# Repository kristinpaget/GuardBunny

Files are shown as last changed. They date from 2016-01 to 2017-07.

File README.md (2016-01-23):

# GuardBunny
## An active RFID shield

**tl;dr: Send the contents of the "Manufacturing" folder to any PCBA shop and they should be able to make you a batch of GuardBunnies.**

In this repository:

- Eagle Files:

Schematic, PCB layout, and library for the counter chip.  Built with Eagle for Mac 7.5.0.

- Logo

GuardBunny logo design

- Manufacturing

Gerber files (including Excellon drill data), Bill of Materials, component placement co-ordinates.

- Presentation

The slides.  Link to follow to video of the talk.

- schematic.png

Exactly what it says on the tin :D

If you would be interested in joining a group order for GuardBunnies, send me an email at iwantabunny@tombom.co.uk and tell me how many you'd like - bear in mind they'll be $15-20 each unless we can get some quantity going.

Released under Creative Commons license Attribution-ShareAlike 4.0 International (CC BY-SA 4.0) - http://creativecommons.org/licenses/by-sa/4.0/

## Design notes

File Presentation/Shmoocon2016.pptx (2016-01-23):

## Be Free, Little Guardbunny!

Presented at Shmoocon 2016

- Kristin Paget
- Director of Security Data Cloud

- kristin@tombom.co.uk
- kpaget@salesforce.com
- @kristinpaget

## Much love and many thanks

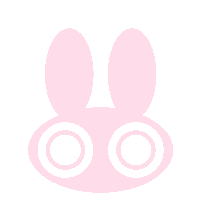
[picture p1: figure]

- JP Martin
- Henry and the Recursion crew
- Salesforce
- All the engineers that I've talked at about this :)
- My wife and her m4d 5MD 5k1llz <3

## Theory

## What is GuardBunny?

- An active RFID shield.
  - Conventional shields attempt to block the signal
    - Stronger signals saturate and eventually penetrate
  - GuardBunny absorbs the signal and uses it
    - Stronger signals? No problem!
- It's a lot like an RFID tag
  - In a lot of ways it is an RFID tag
  - In other ways...not so much :)
- NB: “RFID” = “Contactless” = “NFC” = “WTFEver”.
  - As long as it's at 13.56MHz

## GuardBunny vs RFID

Source: placeholder

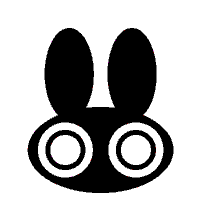
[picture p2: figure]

| | MIFARE Classic | iClass
Passively powered, active device | ✔ | ✔ | ✔
Communicates via load modulation | ✔ | ✔ | ✔
Memory | 4 bits | Up to 4K | Up to 4K
Non-volatile storage | ✘ | ✔ | ✔
Has CPU | ✘ | ✔ | ✔

## Flow of Operation

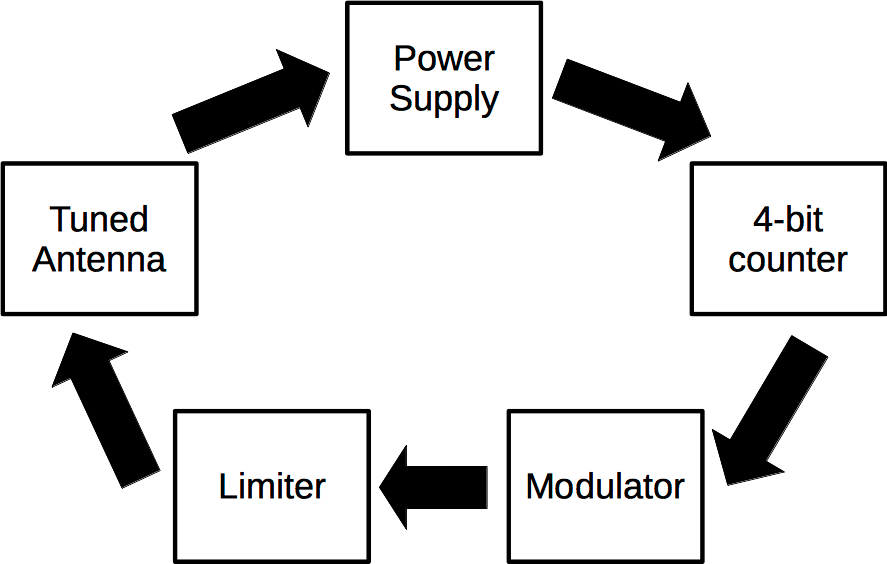
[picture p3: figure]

## Why a 4-bit counter?

- ISO 14443 specifies an ~847KHz subcarrier
  - A.K.A. fc/16 = carrier frequency / 16
  - 1 bit duration = 8 periods of the subcarrier
- In these systems fc/16 is critical
- 4 bit counter = 16 possible states
- 16 states into a modulator gives you fc/16
- GuardBunny speaks ISO14443! :)

## So what’s with the fc/16?

- The tag communicates via fc/16
- GuardBunny outputs fc/16
- GuardBunny doesn't have to be loudest
  - If it can flip a single bit, it wins
  - If it can de-sync the reader's timing, it wins
  - If it can confuse the reader at all, it wins
- Loud enough to be heard is good enough.

## Electrical

## Schematic

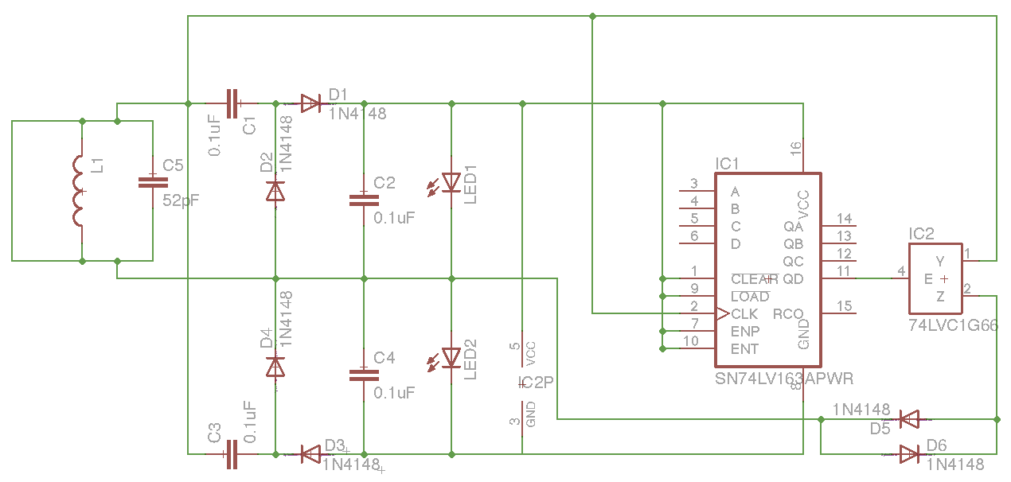
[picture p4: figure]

## Stage 1: Antenna

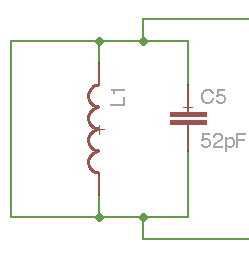
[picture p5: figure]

- Nothing too special
- Shorted for the PCB layout
  - Electrically, it kinda is
- Tuning is tricksy.
  - But critical!
  - Use another PCB to tune.

## Stage 2: Power Supply

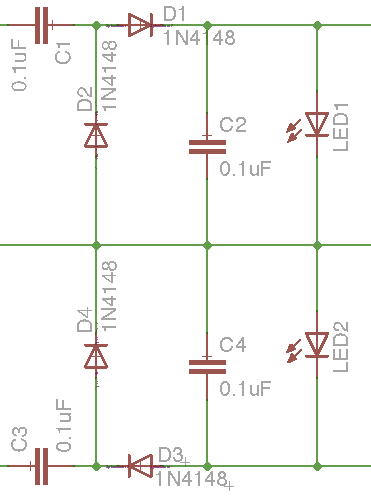
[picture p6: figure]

- Two halves of a full-wave rectifier
  - The middle line is “ground”
- C1 & C3 decouple the supply
- D2&4 compensate for D1&3
  - While doubling voltage
  - 2 phases doubles voltage again
- C2 & C4 are tanks
- LED1 & 2 act as voltage limiters
- Very low drop-out

## Stage 3: 4-bit counter

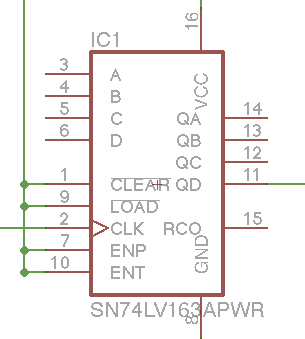
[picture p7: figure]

- 74LV163, but any binary counter is fine
- Key specification rating: Turn-on voltage
  - (74LV is 2V)
- Check datasheets for weird pins
- Make sure it'll take a 13.56MHz clock...

## Stage 4: Modulator

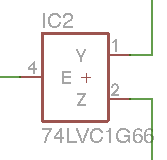
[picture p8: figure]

- “Analog switch”
- Switching speed and voltage rating are crucial
- When E is high, short Y and Z together.
- Y and Z go to coil, E now load-modulates

## Stage 5: Limiter

- The counter gets its clock from the coil
- If the coil is shorted there is no clock!
- Solution: don't short the coil completely.
- D5 & D6 guarantee at least 0.7V on the coil

## Schematic Redux

## Demo

## Improvements

## That’s v1. What would v2 look like?

- Antenna geometry matching
  - PSU trickery
- Counter chip input impedance
  - Constant-current regulators to the rescue!
- Modulator logic
  - Different approaches
- Power supply
  - Switchmode for lower dropout?
- Additional alerts

## Capturing the Flux

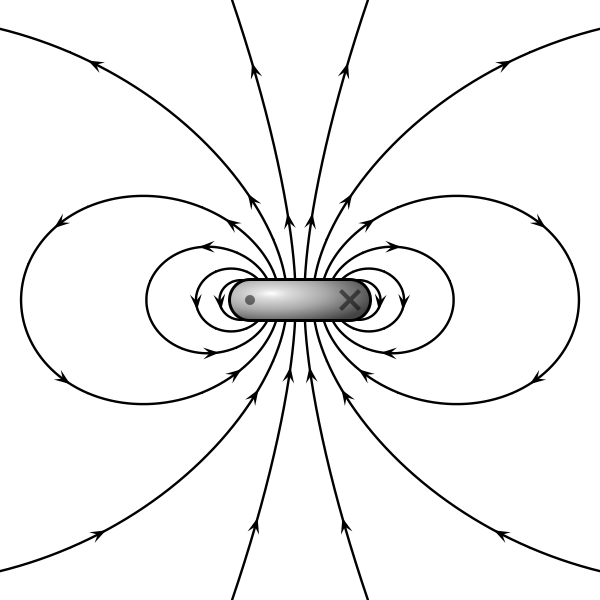
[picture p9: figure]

- Magnetic field lines flow through the coil
- If coils don't match, not all flux is matched
- If flux is mismatched, power is mismatched
- Power the tag but not GuardBunny :(

## Solution: Antenna arrays

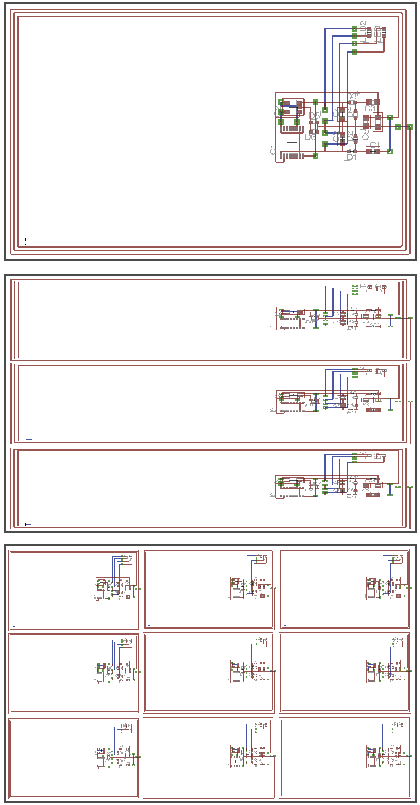
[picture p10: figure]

- Use lots of antennas!
- Crude: Multiple GuardBunny circuits per instance
- Better: give each antenna a PSU, combine in series
- Ultimate: Manipulate phase and combine at the antenna.
- Once powered, modulate all the antennas as one

## Counter input

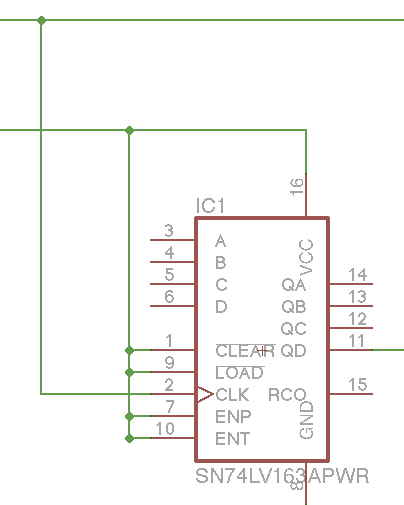
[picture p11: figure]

- Counter chip gets its clock directly from the coil
- Not a problem unless power is high
  - The LEDs ultimately limit coil voltage
- Protection diodes shunt away the excess
  - Killing our modulation depth in the process
- Loss of good power for no signal benefit

## Solution: Impedance trickery

- We want low impedance at low voltage
- We want the chip to turn on quickly
- We want high impedance at high voltage
- We don't want excess voltage reaching the chip
- We also don't want power from the coil to be shunted
- Simple PSU approaches don’t work!

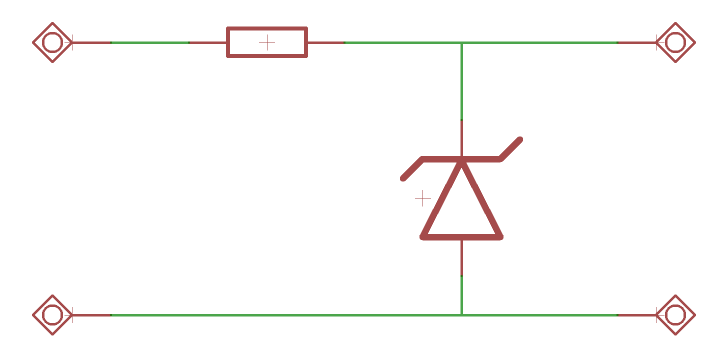
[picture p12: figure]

## Constant current regulator

- Converts constant V to constant I
- Set I very low (input impedance is known)
- Use something better than a 7805
  - Some kind of LDO regulator, probably
- Output voltage is odd
  - Efficiency vs logic thresholds

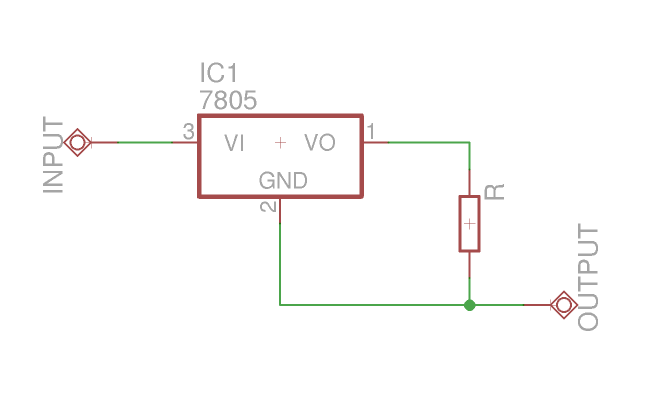
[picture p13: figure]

## Modulator logic

- The current logic:
  - If PSU is overcharged, discharge through LEDs
  - If the modulator is on, short-circuit the coil (+/- lim)
- At high energy, too much power goes to LEDs
- An alternate approach:
  - Allow PSU to charge endlessly
  - Modulator dumps power from PSU into LEDs
  - PSU recharge current back-propagates to coil
  - Phase shifts might cause problems (or fun!)

## Power supply

- The present combination works well
  - No uncompensated voltage drops, high efficiency, 4x multiplier
- Could avoid dumping power to LEDs
  - Same constant current trickery as for counter
- Could go for a higher multiplier
  - Tradeoff: more caps and diodes. Not too bad. Useful?
- Switchmode might help low-end performance
  - Very tricksy to design
- Still might get killed by lack of power

## Alerting options

- Extend the counter - bit 10 is audio
  - Several good tones at Q10-14, choose or combine
    - (Q16 && Q10) || (!Q16 && Q11) == 2-tone siren!
  - Drive a piezo with them!
- Should be enough power to drive a BLE chip
  - Increase PSU caps to stay alive longer if needed
- Lots of UI possibilities in a card form factor
  - Screen showing event count?
  - Button to disable device?

## Failure Modes

- Antennas don't match
  - Can't ever be perfect. Does “good enough” exist?
- Way, WAY too much power
  - LEDs will likely die first, releasing PSU voltage
  - Chips die pretty soon after == no more fc/16
  - Finally, PSU caps are rated at 25V (magic smoke?)
  - Use a high-voltage zener to protect against this
    - Dies eventually – but so will the tag.
- DSP to separate GB modulation from tag
- Static electricity (the counter chip is sensitive)

## Build

## Build a Batch of Bunnies

- It's designed to fit into a clamshell case
  - Counter IC is TSSOP – 1.2mm thick
  - Flex PCBs will fit, FR4 probably not
- Production costs (approx):
  - $100 / board in qty 10 (not including assembly)
  - $10 / board in qty 1,000 (including assembly)
  - $5 / board in qty 10,000 (including assembly)
- None of the parts are particularly tricksy
  - 0603 caps, SOD523 diodes, SOT23-5 modulator

## Component Selection

- Tuning caps are sensitive! Use 1%, C0G, 100V
- PSU caps not so sensitive. 10V+, 0.1uF+
- Diodes: Fast recovery is key, ideally a few ns
  - 1N4148 works fine at 4ns, but could be improved
  - Make sure your limiter diode Vf will allow clock to tick!
- Counter: Low-voltage turnon is crucial. TSSOP.
  - Any old 4-bit binary counter will work though!
- Modulator: Check voltage / current ratings.

## Component selection: LEDs

- Start by checking voltage ratings on chips
- Each LED shunts half the supply voltage
  - This sets the maximum forward voltage allowed
- Tradeoff: forward voltage
  - Higher Vf means GuardBunny is more effective
  - Lower Vf means that the LEDs turn on sooner
- Tradeoff: forward current
  - Higher If means brighter lights
  - Lower If means more effective but vulnerable to high power

## Conclusions

- It's a v1, proof-of-concept device.
- It works, but has (fixable) weaknesses
- My opinion:
  - Not yet worthy of selling as a product
  - Definitely worthy of talking about :)
- Lots of work to do – help appreciated!

## Questions?

Schematic, layout, BOM, gerbers, logos etc:
https://github.com/kristinpaget/GuardBunny

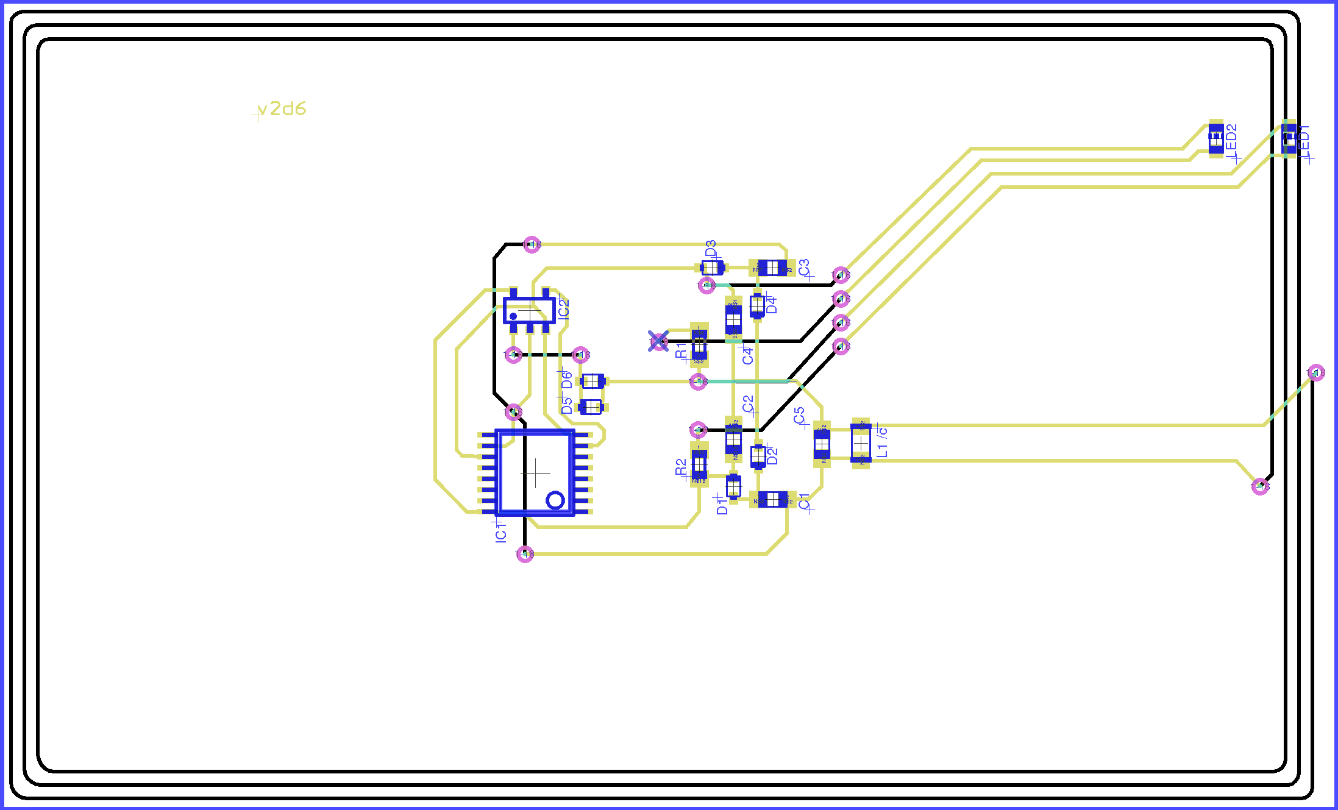
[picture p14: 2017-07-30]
DC25/GB_v2d6_layout_big.png

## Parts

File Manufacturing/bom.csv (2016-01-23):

Description | Qty | Ref des | MFG P/N | MFG | Mouser P/N
MLCC 0.1uF 25V 0603 | 4 | C1, C2, C3, C4 | VJ0603V104ZXXCW1BC | Vishay | 77-VJ0603V104ZXXCBC
MLCC 200pF 100V C0G 0603 | 1 | C5 | GRM1885C2A201JA01D | Murata | 81-GRM1885C2A201JA1D
Diode 1N4148X | 6 | D1, D2, D3, D4, D5, D6 | 1N4148X-TP | MCC | 833-1N4148X-TP
74LV163 4-bit counter | 1 | IC1 | SN74LV163APWR | TI | 595-SN74LV163APWR
74LVC1G66 analog switch | 1 | IC2 | SN74LVC1G66DBVR | TI | 595-SN74LVC1G66DBVR
DNP | 1 | L1 | DNP | DNP | DNP
RED LED | 2 | LED1, LED2 | LS Q976-NR-1 | OSRAM | 720-LSQ976-NR-1

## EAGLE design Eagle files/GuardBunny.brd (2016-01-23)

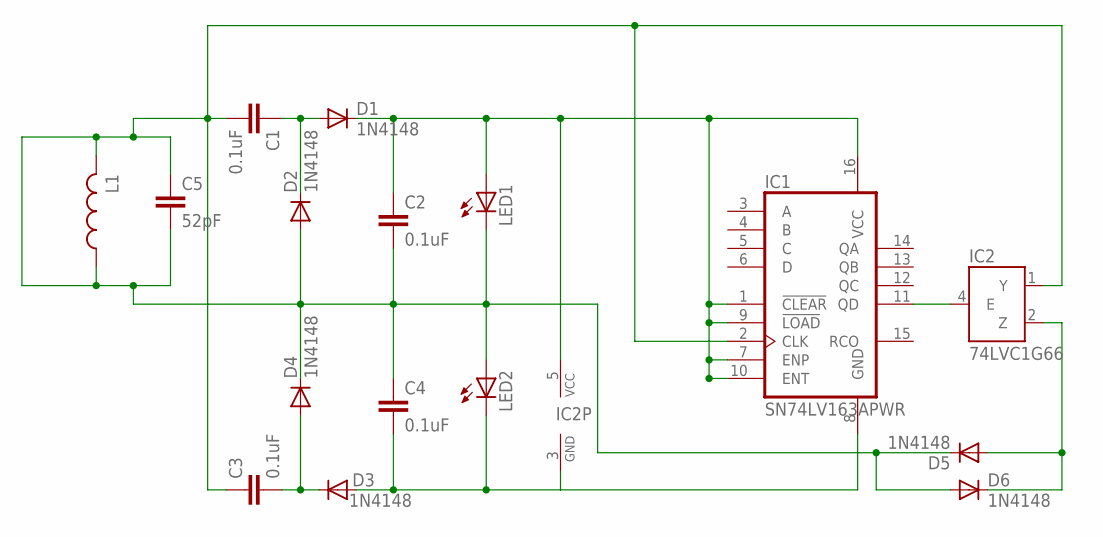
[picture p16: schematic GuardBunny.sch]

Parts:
C1, C2, C3, C4: 0.1uF; C0603
C5: 52pF; C0603
D1, D2, D3, D4, D5, D6: 1N4148; SOD523
IC1: SN74LV163APWR; TSSOP16
IC2: 74LVC1G66; SOT23-5
L1: L-USL2012C; L2012C
LED1, LED2: LEDCHIP-LED0603; CHIP-LED0603

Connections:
GND: C4.2, D3.A, IC1.8 (GND), IC2.3 (GND), LED2.C
unnamed: C1.2, C2.2, C3.1, C4.1, C5.1, C5.2, D2.A, D4.C, D5.C, D6.A, IC1.2 (CLK), IC2.1 (Y), L1.1, L1.2, LED1.C, LED2.A
unnamed: C1.1, D1.A, D2.C
unnamed: IC1.11 (QD), IC2.4 (E)
unnamed: C3.2, D3.C, D4.A
unnamed: D5.A, D6.C, IC2.2 (Z)
VCC: C2.1, D1.C, IC1.1 (!CLEAR), IC1.7 (ENP), IC1.9 (!LOAD), IC1.10 (ENT), IC1.16 (VCC), IC2.5 (VCC), LED1.A

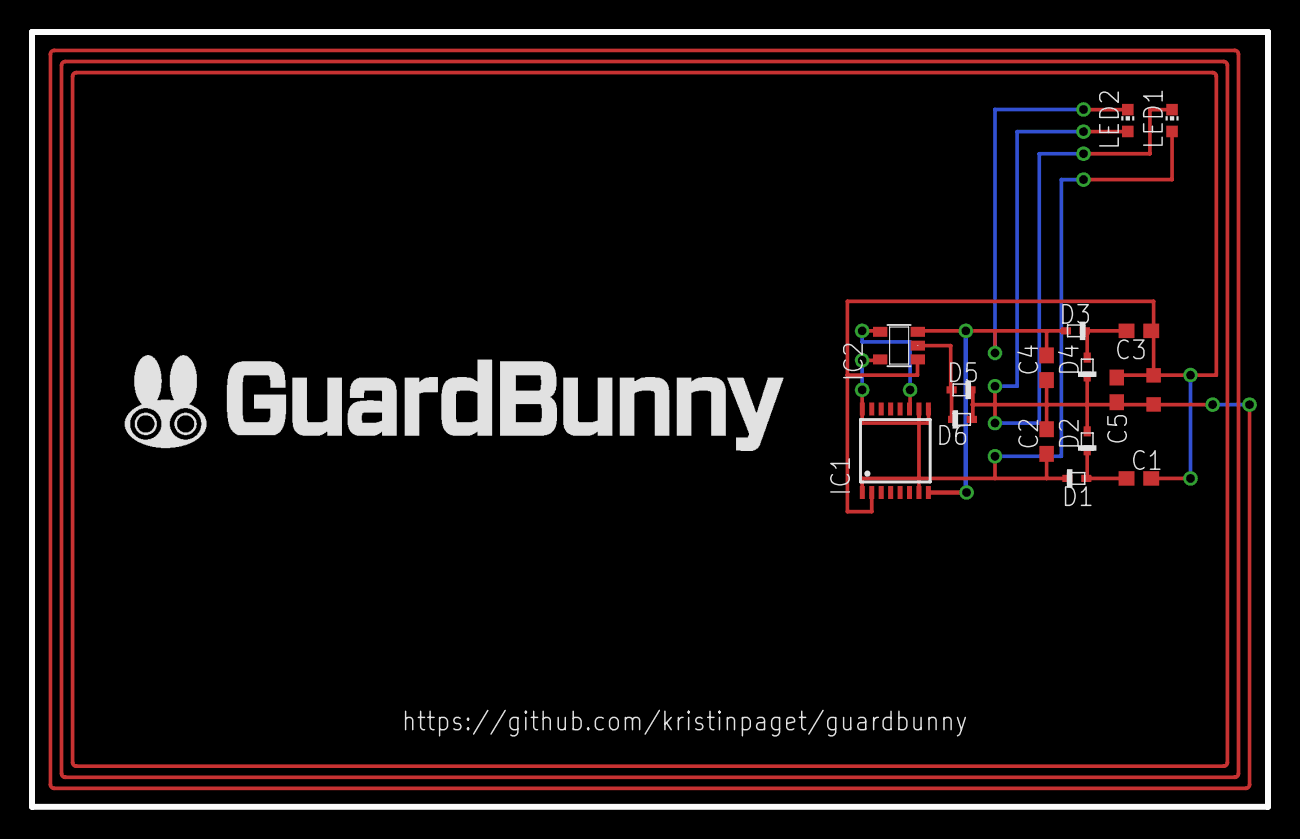
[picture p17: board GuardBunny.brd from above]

Board: 2 copper layers, 85.1 x 53.3 mm, 16 parts (0 on the bottom side), 7 nets.
